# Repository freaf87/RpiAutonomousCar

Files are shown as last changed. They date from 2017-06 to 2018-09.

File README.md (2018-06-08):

Rpi Autonomous Car PCB 
====================
This board bring those additional functions below to the Raspberry pi:

	 - Analog Digital Converter with MCP3008 (8)
	 - DC Brushed Motor driver (2) with TB6612FNG
	 - Level converted IOs (5V <-> 3.3V) (8)
     - 16-channel, 12-bit PWM with PCA9685
     - RGB LED (1)
     - Pushbutton (1)

Top                                                                      |  Bottom
:-----------------------------------------------------------------------:|:--------------------------------------------------------------:
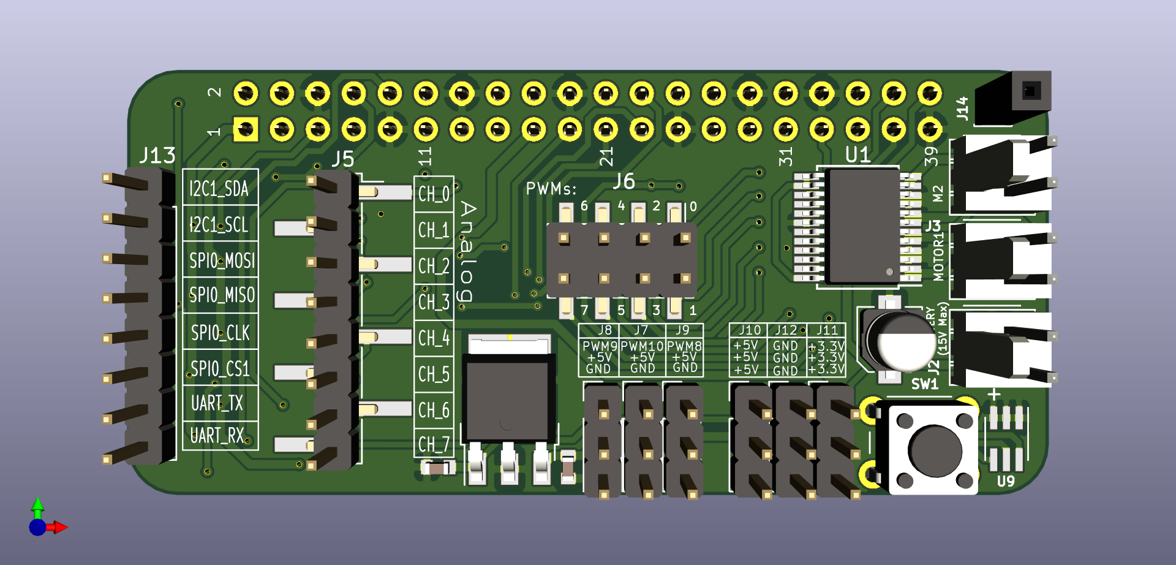
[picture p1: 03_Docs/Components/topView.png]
Top
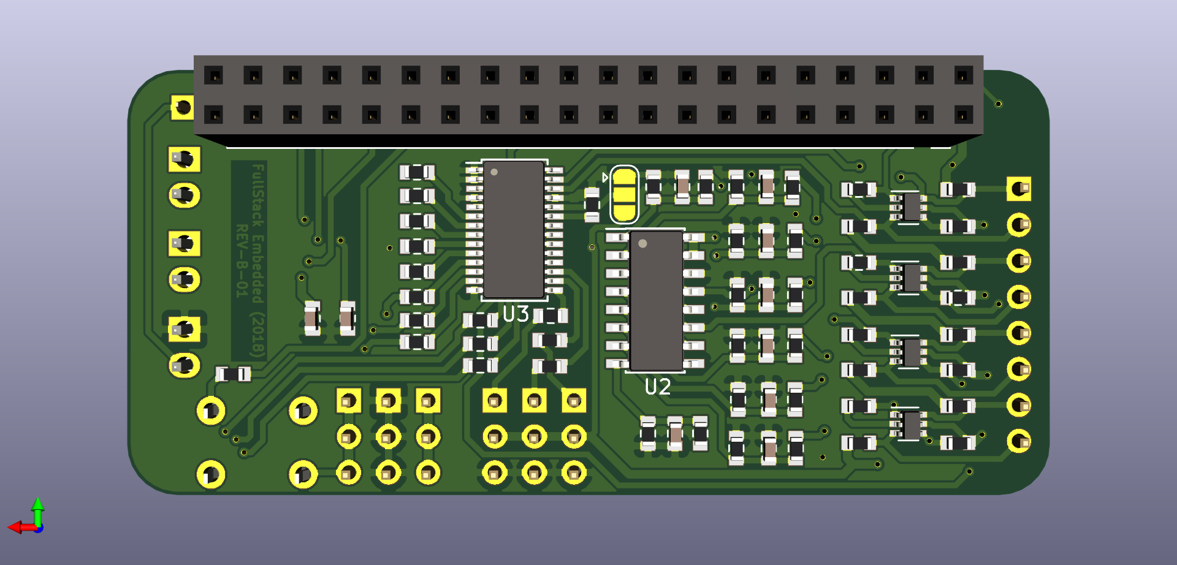
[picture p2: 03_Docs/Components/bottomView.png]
Bottom
  |  

Author: Frederic Afadjigla, 2018

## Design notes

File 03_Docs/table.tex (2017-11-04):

\begin{table}[htbp]
\caption{AutonomousCarPinout}
\begin{center}
\begin{tabular}{|c|c|c|c|c|c|}
\hline
\textbf{Pin number} & \textbf{Pin name} & \textbf{Pin type} & \textbf{Primary function} & \textbf{Level converted} & \textbf{Additional functions} \\ \hline
3 & GPIO 02 & I/O & I2C1 SDA  & JP1/5 &  \\ \hline
5 & GPIO 03 & I/O & I2C1 SCL  & JP1/6 &  \\ \hline
7 & GPIO 04 & I/O &  & - & SERVO PWM \\ \hline
8 & GPIO 14 & I/O & UART0 TX & JP1/7 &  \\ \hline
10 & GPIO 15 & I/O & UART0 RX & JP1/8 &  \\ \hline
11 & GPIO 17 & I/O &  & - &  \\ \hline
12 & GPIO 18 & I/O &  & - & ANTENNA\_1 \\ \hline
13 & GPIO 27 & I/O &  & - & ANTENNA\_2 \\ \hline
15 & GPIO 22 & I/O &  & - &  \\ \hline
16 & GPIO 23 & I/O &  & - &  \\ \hline
18 & GPIO 24 & I/O &  & - &  \\ \hline
19 & GPIO 10 & I/O & SPI0 MOSI & JP1/1 & ADC\_MOSI \\ \hline
21 & GPIO 09 & I/O & SPI0 MISO & JP1/2 & ADC\_MISO \\ \hline
22 & GPIO 25 & I/O &  & - & ADC\_CS \\ \hline
23 & GPIO 11 & I/O & SPI0 CLK & JP1/3 & ADC\_CLK \\ \hline
24 & GPIO 08 & I/O & SPI0 CS & JP1/4 &  \\ \hline
26 & GPIO 07 & I/O &  & - &  \\ \hline
29 & GPIO 05 & I/O &  & - & M1\_PWM \\ \hline
31 & GPIO 06 & I/O &  & - & M1\_DIR\_1 \\ \hline
32 & GPIO 12 & I/O &  & - & M1\_DIR\_2 \\ \hline
33 & GPIO 13 & I/O &  & - & STBY \\ \hline
35 & GPIO 19 & I/O &  & - & M2\_DIR\_1 \\ \hline
36 & GPIO 16 & I/O &  & - & M2\_DIR\_2 \\ \hline
37 & GPIO 26 & I/O &  & - & M2\_PWM \\ \hline
38 & GPIO 20 & I/O &  & - &  \\ \hline
40 & GPIO 21 & I/O & \multicolumn{1}{l|}{} & - & USER LED \\ \hline
\end{tabular}
\end{center}
\label{AutonomousCarPinout}
\end{table}

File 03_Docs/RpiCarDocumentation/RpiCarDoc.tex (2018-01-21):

\documentclass[
12pt, % Main document font size
a4paper, % Paper type, use 'letterpaper' for US Letter paper
oneside, % One page layout (no page indentation)
%twoside, % Two page layout (page indentation for binding and different headers)
headinclude,footinclude, % Extra spacing for the header and footer
BCOR5mm, % Binding correction
table,
]{scrartcl}

\input{structure.tex} % Include the structure.tex file which specified the document structure and layout

\hyphenation{Fortran hy-phen-ation} % Specify custom hyphenation points in words with dashes where you would like hyphenation to occur, or alternatively, don't put any dashes in a word to stop hyphenation altogether

%----------------------------------------------------------------------------------------
%	TITLE AND AUTHOR(S)
%----------------------------------------------------------------------------------------

\title{\normalfont\spacedallcaps{RPi based autonomous Car}} % The article title
\author{\spacedlowsmallcaps{Fullstack Embedded (2017)} \\\spacedlowsmallcaps{Frederic Afadjigla}} 
\date{} % An optional date to appear under the author(s)

%----------------------------------------------------------------------------------------

\usepackage{graphicx}
\begin{document}

%----------------------------------------------------------------------------------------
%	HEADERS
%----------------------------------------------------------------------------------------

\renewcommand{\sectionmark}[1]{\markright{\spacedlowsmallcaps{#1}}} % The header for all pages (oneside) or for even pages (twoside)
%\renewcommand{\subsectionmark}[1]{\markright{\thesubsection~#1}} % Uncomment when using the twoside option - this modifies the header on odd pages
\lehead{\mbox{\llap{\small\thepage\kern1em\color{halfgray} \vline}\color{halfgray}\hspace{0.5em}\rightmark\hfil}} % The header style

\pagestyle{scrheadings} % Enable the headers specified in this block

%----------------------------------------------------------------------------------------
%	TABLE OF CONTENTS & LISTS OF FIGURES AND TABLES
%----------------------------------------------------------------------------------------
\maketitle % Print the title/author/date block

\setcounter{tocdepth}{2} % Set the depth of the table of contents to show sections and subsections only

\tableofcontents % Print the table of contents
\listoffigures % Print the list of figures
%\listoftables % Print the list of tables

%----------------------------------------------------------------------------------------
%	ABSTRACT
%----------------------------------------------------------------------------------------

\section*{Abstract} % This section will not appear in the table of contents due to the star (\section*)
The purpose of this document is to give the reader an overview about the RpiAutonomousCar's hardware. This will be the learning platform for the FSE 2017 Workshop in Lomé and Accra. The principal hardware components of the board and interfaces will be briefly described.

%
\newpage
%

%----------------------------------------------------------------------------------------
%	INTRODUCTION
%----------------------------------------------------------------------------------------

\section{Introduction}
Goal of FSE 2017 will be to build an autonomous car with obstacle avoidance capability with the students. The robot should be able to drive 2 brushed DC motors, an ultrasonic sensor for distance measurement and a servo motor. To be able to fullfill these requirements with a Raspberry Pi, an additional board will be designed.

%----------------------------------------------------------------------------------------
%	MECHANIC
%----------------------------------------------------------------------------------------

\section{RpiAutonomousCar's mechanic}
As shown in Figure~\vref{fig:Mechanic1} and ~\vref{fig:Mechanic2}, the mechanical structure is simple and easy to build. The kit includes:
\begin{itemize}
\item 1 x Car Chassis 
\item 2 x Gear Motor(1:48) 
\item 2 x Car Tire 
\item 2 x Speed Encoder 
\item 2 x Fastener 
\item 1 x Universal Wheel 
\item 1 x Battery Box 
\item All Necessary Screw And Nut
\end{itemize}

\begin{figure}[h]
\minipage{0.48\textwidth}
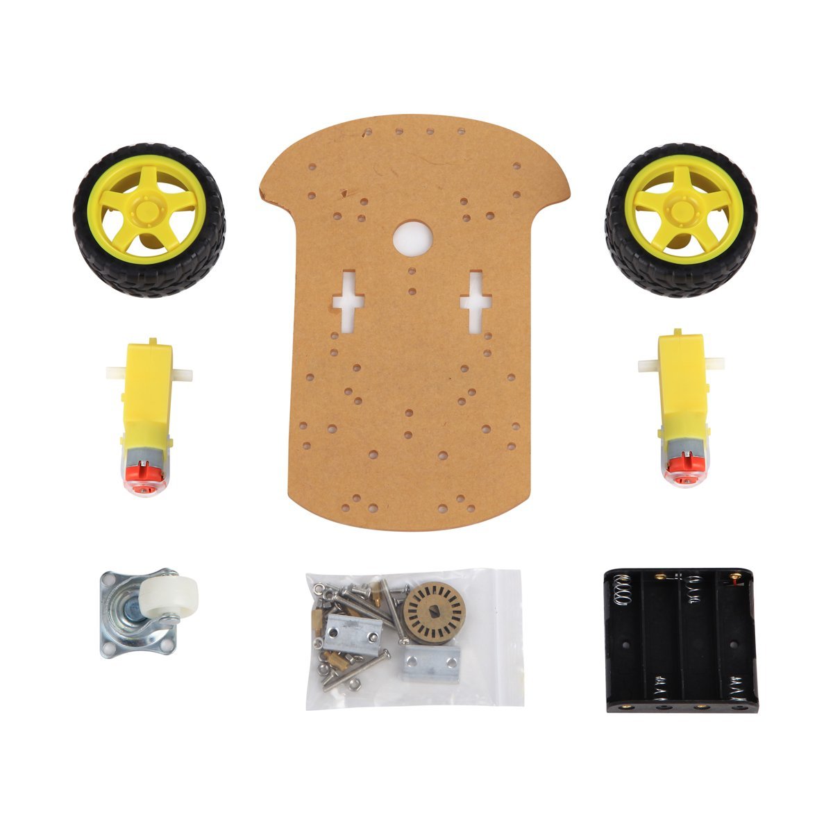
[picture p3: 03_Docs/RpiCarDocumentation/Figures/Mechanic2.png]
  
  \caption{Robot's components}\label{fig:Mechanic2}
\endminipage\hfill
\minipage{0.48\textwidth}
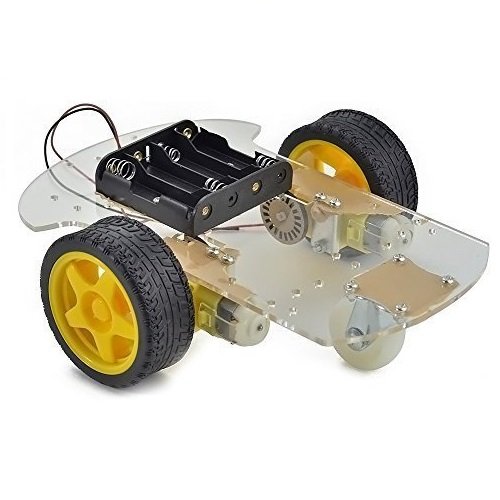
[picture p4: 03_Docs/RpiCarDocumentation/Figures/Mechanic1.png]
  
  \caption{Assembled robot}\label{fig:Mechanic1}
\endminipage
\end{figure}

%----------------------------------------------------------------------------------------
%	ELECTRONIC
%----------------------------------------------------------------------------------------
\section{RpiAutonomousCar's electronic}
The Board's electronic is kept simple to ease training. It is designed so that students can use the same board to design other embedded system examples.

\subsection{Led}
The RpiAutonomousCar's board has one led connected to GPIO21.

\begin{figure}[H]
\centering
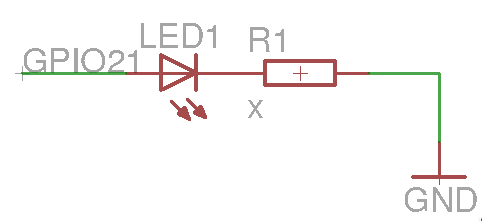
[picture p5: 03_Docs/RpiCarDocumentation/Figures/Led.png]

\caption{Led}
\label{Led}
\end{figure}

\subsection{Analog Inputs for Raspberry Pi Using the MCP3004}
The MCP3004 is a low cost 4-channel 10-bit analog to digital converter. The MCP3004 connects to the Raspberry Pi using a serial peripheral interface (SPI) serial connection. You can use either the hardware SPI bus (remember to connect GPIO07 and GPIO25 together via a jumper cable if you have the first version of the board), or any four GPIO pins and software SPI to communicate to the MCP3004. Software SPI is a little more flexible since it can work with any pins on the Pi, whereas hardware SPI is slightly faster but less flexible because it only works with specific pins. The board gives you the possibility to try both methods since it is also wired to the Raspberry Pi hardware SPI.

\begin{figure}[h]
\centering
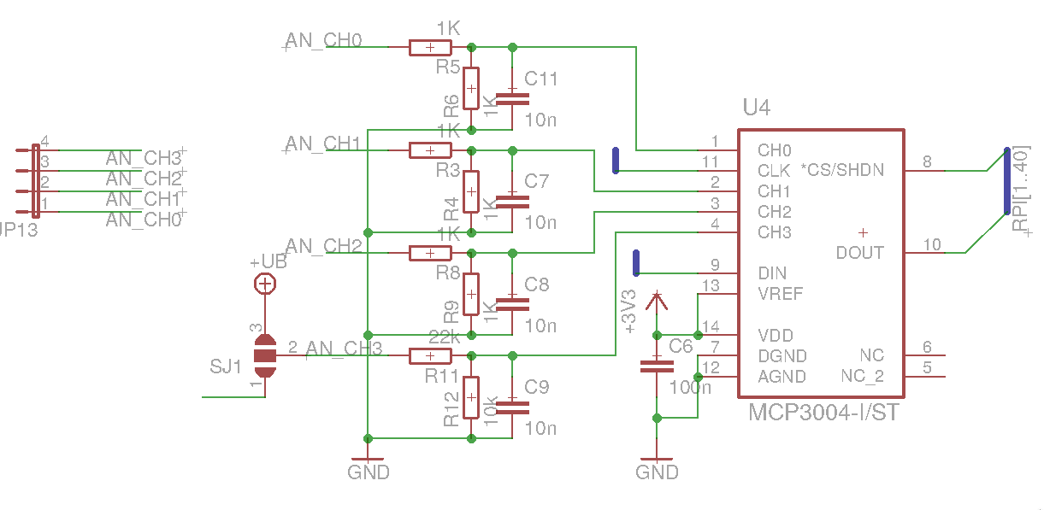
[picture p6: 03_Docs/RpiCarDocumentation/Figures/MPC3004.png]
 
\caption[MPC3004 schematic]{MPC3004 schematic}
\label{fig:MPC3004}
\end{figure}

\begin{table}[H]
\centering
\begin{tabular}{lr}
\hline
SPI Pins & Raspberry Pi pin \\
\hline
SCLK (Serial Clock)        & GPIO11 \\
MOSI (Master Out Slave In) & GPIO10 \\
MISO (Master In Slave Out) & GPIO09 \\
CS   (Chip Select)         & GPIO25 \\
\hline
\end{tabular}
\label{tab:label}
\caption{MCP3004 SPI connection}
\end{table}
Voltage that are allowed to be connected to the MCP3004 have to be selected so that \(V_{out}\) muss be less than 3.3V(\(V_{ref}\)). \(V_{out}\) is the voltage that can be measured after the voltage dividers. All channels except channel 3 are designed to have a measuring range of 0-5V DC. Channel 3 can measure up to 10V.
\(V_{out[0-2]}\) for channels 0,1,2 can be calculated as:

\[ V_{ out[0-2] } = \frac{ R_{6} }{ R_{5} + R_{6} } * V_{in}  = 0.5* V_{in}\]

In case of channel 3:

\[ V_{out[3]} = 0.316 * V_{in}\]

Please note that the analog channel 3 is connected per default via a jumper (SJ1) to the robot's supply voltage. Remove the jumper to be able to connect another voltage source to channel 3. 

\subsection{8-channel Bi-directional Logic Level Converter - TXB0108}
Precautions have to be taken when connecting 5V devices to the raspberry pi since the Pi is not 5V tolerant. There are many simple ways to handle this issue like voltage dividers.Handling bidirectional signals or high speed transfers can be tough. That's where this lovely chip, the TXB0108 bi-directional level converter comes in! This chip performs bidirectional level shifting from pretty much any voltage to any voltage and will auto-detect the direction.  

\begin{figure}[h]
\centering
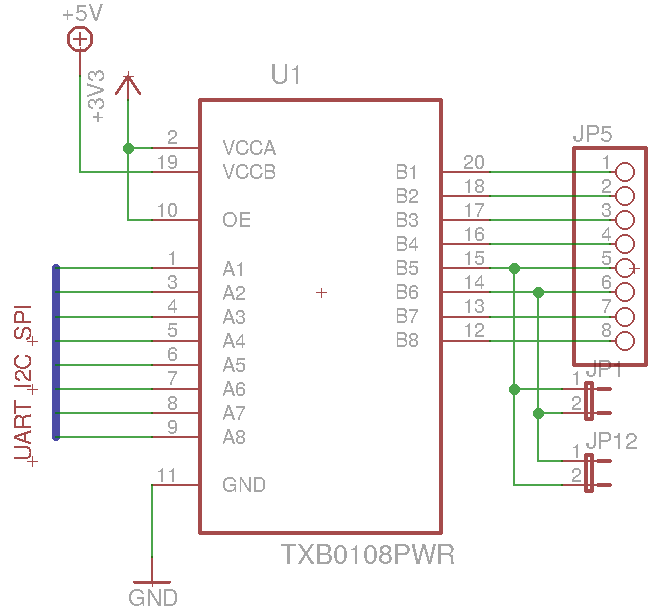
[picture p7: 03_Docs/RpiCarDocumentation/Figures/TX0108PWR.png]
 
\caption[TX0108PWR schematic]{TXB0108PWR schematic}
\label{fig:TX0108PWR}
\end{figure}

\begin{table}[H]
\centering
\begin{tabular}{|cc|}
\hline
Pins & RPi pin \\
\hline
1  & GPIO10 \\
2  & GPIO09 \\
3  & GPIO11 \\
4  & GPIO08 \\
5  & GPIO02 \\
6  & GPIO03 \\
7  & GPIO14 \\
8  & GPIO15 \\
\hline
\end{tabular}
\label{tab:label}
\caption{TX0108PWR connection}
\end{table}
\subsection {DC Motor driver - TB6612FNG}
The TB6612FNG motor driver can control up to two DC motors at a constant current of 1.2A (3.2A peak). Two input signals (IN1 and IN2) can be used to control the motor in one of four function modes - clockwise (CW), counter-clockwise (CCW), short-brake, and stop. The two motor outputs (A and B) can be separately controlled, the speed of each motor is controlled via a PWM input signal with a frequency up to 100kHz. The STBY pin should be pulled high to take the motor out of standby mode.

Logic supply voltage (VCC) can be in the range of 2.7-5.5VDC, while the motor supply (VM) is limited to a maximum voltage of 15VDC. The output current is rated up to 1.2A per channel (or up to 3.2A for a short, single pulse).\\

Features:
\begin{itemize}
\item[•] Power supply voltage: VM=15V max, VCC=2.7-5.5V
\item[•] Output current: Iout=1.2A(average) / 3.2A (peak)
\item[•] Standby control to save power
\item[•] CW/CCW/short brake/stop motor control modes
\item[•] Built-in thermal shutdown circuit and low voltage detecting circuit
\item[•] All pins of the TB6612FNG broken out to 0.1" spaced pins
\item[•] Filtering capacitors on both supply lines
\end{itemize}

\begin{figure}[H]
\centering
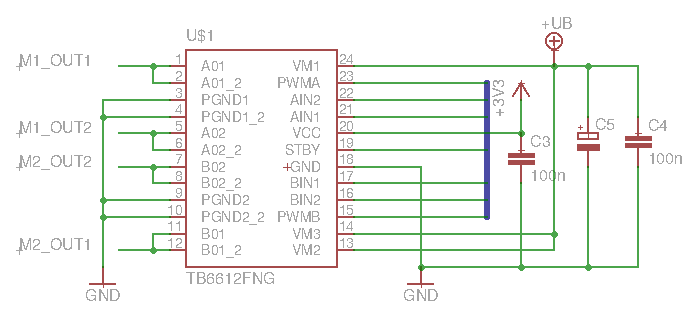
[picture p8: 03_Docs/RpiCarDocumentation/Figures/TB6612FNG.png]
 
\caption[TB6612FNG schematic]{TB6612FNG schematic}
\label{fig:TB6612FNG}
\end{figure}
Let’s discuss the pinout for the TB6612FNG:

\newcolumntype{b}{X}
\newcolumntype{s}{>{\hsize=.3\hsize}X}
\newcolumntype{m}{>{\hsize=.5\hsize}X}

\begin{table}[H]
\centering
\begin{adjustwidth}{-1cm}{}
\resizebox{16cm}{!} {%
\begin{tabularx}{18cm}{smb}
\hline
Pin Label & Function & Notes \\
\hline
VM & Motor Voltage  & This is where you provide power for the motors (2.2V to 13.5V)\\
VCC & Logic Voltage & This is the voltage to power the chip and talk to the microcontroller (2.7V to 5.5V)\\
GND & Ground  & Common Ground for both motor voltage and logic voltage (all GND pins are connected)\\
STBY & Standby & Allows the H-bridges to work when high (has a pulldown resistor so it must actively pulled high)\\
AIN1/BIN1 & Input 1 for channels A/B   & One of the two inputs that determines the direction\\
AIN2/BIN2 & Input 2 for channels A/B   & One of the two inputs that determines the direction\\
PWMA/PWMB & PWM input for channels A/B & PWM input that controls the speed\\
A01/B01 & Output 1 for channels A/B  & One of the two outputs to connect the motor\\
A02/B02 & Output 2 for channels A/B  & One of the two outputs to connect the motor\\
\hline
\end{tabularx} } 
\end{adjustwidth}
\label{tab:label}
\caption{TB6612FNG connection}
\end{table}

When the outputs are set to High/Low your motor will run. When they are set to Low/High the motor will run in the opposite direction. In both cases, the speed is controlled by the PWM input.

\begin{table}[H]
\centering
\begin{tabular}{llllll}
\hline
In1  & In2 & PWM & Out1 & Out2 & Mode \\
\hline
H    & H   & H/L & L    &L     & Short brake\\
L    & H   & H   & L    & H    & CCW\\
L    & H   & L   & L    & L    & Short brake\\
H    & L   & H   & H    & L    & CW\\
H    & L   & L   & L    & L    & Short brake\\
L    & L   & H   & OFF  & OFF  & Stop\\
\hline
\end{tabular}
\caption{TB6612FNG Logic}
\label{tab:label}
\end{table}

\section{Wiring the RpiCar}
\subsection{Connecting Robot's components}

\begin{figure}[H]
\centering
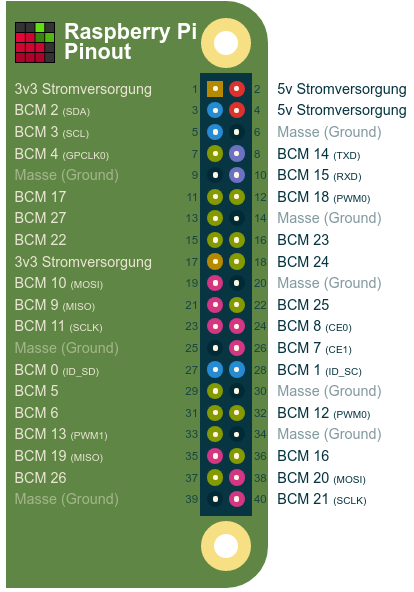
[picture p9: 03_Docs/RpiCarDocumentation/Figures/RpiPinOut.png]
 
\caption[Raspberry Pi Pinout]{Raspberry Pi Pinout \footnotemark}
\label{fig:Raspberry Pi Pinout}
\end{figure}
\footnotetext{\url{https://de.pinout.xyz/pinout/}}

\begin{itemize}

\item Connecting M1 and M2\\
M1 = Motor left and M2 = Motor right
	\begin{figure}[H]
	\centering
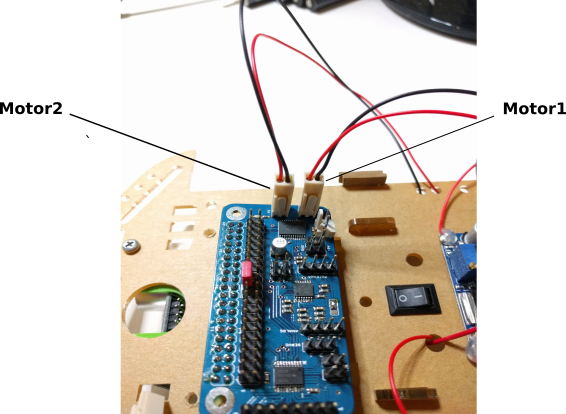
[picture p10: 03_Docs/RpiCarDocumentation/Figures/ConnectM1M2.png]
	
	\caption{Connecting Motor1 and Motor2}
	\label{Connectng Motor1 and Motor2 }
	\end{figure}
	
\item Connecting Motors PWR and Rpi PWR \\
	\begin{figure}[H]
	\centering
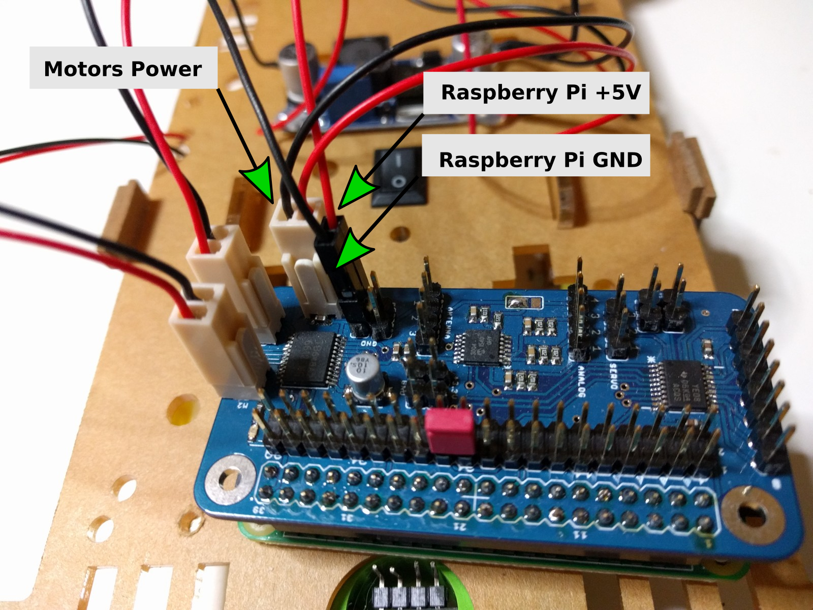
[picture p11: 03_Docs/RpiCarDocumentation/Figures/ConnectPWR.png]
	
	\caption{Connecting Motors PWR and Rpi PWR}
	\label{Connecting Motors PWR and Rpi PWR }
	\end{figure}

\item Connecting Motor Driver Pins\\
Note: Wiring the motor driver is only needed vor V01 of the board. Later releases of the board will incorporate those changes. 

Please connect those pins below together:

    M1 PwmPinAnnex = \textcolor{red}{5}    .......   m1pwmpin = \textcolor{red}{18}
    
    M2 PwmPinAnnex = \textcolor{blue}{26}   .....  m2pwmpin = \textcolor{blue}{13}

\item Connecting the ultrasonic sensor
	\begin{table}[H]
	\centering
	\begin{tabular}{ll}
	\hline
	   Function & Rpi Pin\\
	\hline
		VCC & +5V\\
		TRIG & 15 \textcolor{red}{(Level converted)}\\
		ECHO & 14 \textcolor{red}{(Level converted)}\\
		GND & GND\\
	\hline
	\end{tabular}
	\end{table}
Refer to table ... to find out where GPIO14 and GPIO15 are routed
\item Connecting the IR sensor for line following \\ 
IR sensor can be connected to any available GPIO when used in digital mode. If you want more accuracy analog mode can also be used. Therefore the MCP3004 chip has to be used. Connect the sensor output to the available pins of the MCP3004
\end{itemize}

\end{document}

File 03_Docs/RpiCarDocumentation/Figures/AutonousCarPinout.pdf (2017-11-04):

Sheet1

Pin

n

u

m

b

er

| Pin name | | Primary function | | Additional functions
3 | GPIO 02 | I/O | I2C1 SDA | JP1/5
5 | GPIO 03 | I/O | I2C1 SCL | JP1/6
7 | GPIO 04 | I/O | | - | SERVO PWM
8 | GPIO 14 | I/O | UART0 TX | JP1/7
10 | GPIO 15 | I/O | UART0 RX | JP1/8
11 | GPIO 17 | I/O | | -
12 | GPIO 18 | I/O | | - | ANTENNA_1
13 | GPIO 27 | I/O | | - | ANTENNA_2
15 | GPIO 22 | I/O | | -
16 | GPIO 23 | I/O | | -
18 | GPIO 24 | I/O | | -
19 | GPIO 10 | I/O | SPI0 MOSI | JP1/1 | ADC_MOSI
21 | GPIO 09 | I/O | SPI0 MISO | JP1/2 | ADC_MISO
22 | GPIO 25 | I/O | | - | ADC_CS
23 | GPIO 11 | I/O | SPI0 CLK | JP1/3 | ADC_CLK
24 | GPIO 08 | I/O | SPI0 CS | JP1/4
26 | GPIO 07 | I/O | | -
29 | GPIO 05 | I/O | | - | M1_PWM
31 | GPIO 06 | I/O | | - | M1_DIR_1
32 | GPIO 12 | I/O | | - | M1_DIR_2
33 | GPIO 13 | I/O | | - | STBY
35 | GPIO 19 | I/O | | - | M2_DIR_1
36 | GPIO 16 | I/O | | - | M2_DIR_2
37 | GPIO 26 | I/O | | - | M2_PWM
38 | GPIO 20 | I/O | | -
40 | GPIO 21 | I/O | | - | USER LED

Pin ty

p

e

L

e

v

el c

o

n

v

erte

d

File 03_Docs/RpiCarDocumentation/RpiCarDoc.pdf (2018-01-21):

# R P I B A S E D A U T O N O M O U S C A R

fullstack embedded (2017)

frederic afadjigla

contents

1 | Introduction | 3
2 | RpiAutonomousCar’s mechanic | 3
3 | RpiAutonomousCar’s electronic | 4
3.1 | Led | | 4
3.2 | Analog Inputs for Raspberry Pi Using the MCP3004 | | 4
3.3 | 8-channel Bi-directional Logic Level Converter - TXB0108 . . | 5
3.4 | DC Motor driver - TB6612FNG | | 6
4 | Wiring the RpiCar | 9
4.1 | Connecting Robot’s components | | 9

list of figures

Figure 1 | Robot’s components | | 3
Figure 2 | Assembled robot | | 3
Figure 3 | Led | | 4
Figure 4 | MPC3004 schematic | | 5
Figure 5 | TX0108PWR schematic | | 6
Figure 6 | TB6612FNG schematic | | 7
Figure 7 | Raspberry Pi Pinout | | 9
Figure 8 | Connecting Motor1 and Motor2 | | 10
Figure 9 | Connecting Motors PWR and Rpi PWR | | 10

1

List of Figures 2

abstract

The purpose of this document is to give the reader an overview about the RpiAutonomousCar’s hardware. This will be the learning platform for the FSE 2017 Workshop in Lomé and Accra. The principal hardware components of the board and interfaces will be briefly described.

introduction | 3
1 | introduction

Goal of FSE 2017 will be to build an autonomous car with obstacle avoidance capability with the students. The robot should be able to drive 2 brushed DC motors, an ultrasonic sensor for distance measurement and a servo motor. To be able to fullfill these requirements with a Raspberry Pi, an additional board will be designed.

2 rpiautonomouscar’s mechanic

As shown in Figure 2 and 1, the mechanical structure is simple and easy to build. The kit includes:

- 1 x Car Chassis
- 2 x Gear Motor(1:48)
- 2 x Car Tire
- 2 x Speed Encoder
- 2 x Fastener
- 1 x Universal Wheel
- 1 x Battery Box
- All Necessary Screw And Nut


Figure 1: Robot’s components | Figure 2: Assembled robot

rpiautonomouscar’s electronic | 4
3 | rpiautonomouscar’s electronic

The Board’s electronic is kept simple to ease training. It is designed so that students can use the same board to design other embedded system examples.

3.1 Led

The RpiAutonomousCar’s board has one led connected to GPIO21.

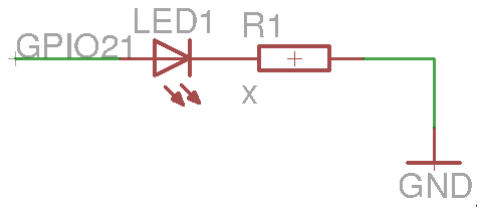
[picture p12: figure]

Figure 3: Led

3.2 Analog Inputs for Raspberry Pi Using the MCP3004

The MCP3004 is a low cost 4-channel 10-bit analog to digital converter. The MCP3004 connects to the Raspberry Pi using a serial peripheral interface (SPI) serial connection. You can use either the hardware SPI bus (remember to connect GPIO07 and GPIO25 together via a jumper cable if you have the first version of the board), or any four GPIO pins and software SPI to communicate to the MCP3004. Software SPI is a little more flexible since it can work with any pins on the Pi, whereas hardware SPI is slightly faster but less flexible because it only works with specific pins. The board gives you the possibility to try both methods since it is also wired to the Raspberry Pi hardware SPI.

SPI Pins | Raspberry Pi pin
SCLK (Serial Clock) | GPIO11
MOSI (Master Out Slave In) | GPIO10
MISO (Master In Slave Out) | GPIO09
CS (Chip Select) | GPIO25

Table 1: MCP3004 SPI connection

Voltage that are allowed to be connected to the MCP3004 have to be selected so that Vout muss be less than 3.3V(Vref). Vout is the voltage that can be measured after the voltage dividers. All channels except channel

rpiautonomouscar’s electronic | 5

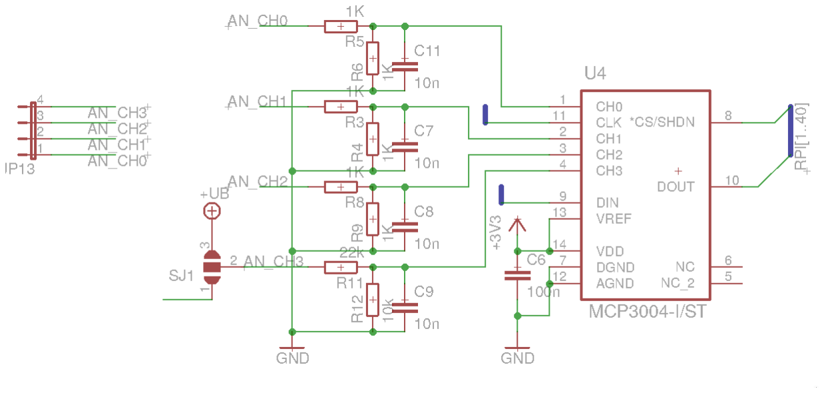
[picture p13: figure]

Figure 4: MPC3004 schematic

3 are designed to have a measuring range of 0-5V DC. Channel 3 can measure up to 10V. Vout[0−2]

for channels 0,1,2 can be calculated as:

Vout[0−2] =

R6
R5 + R6

∗ Vin = 0.5 ∗ Vin

In case of channel 3:

Vout[3] = 0.316 ∗ Vin

Please note that the analog channel 3 is connected per default via a jumper (SJ1) to the robot’s supply voltage. Remove the jumper to be able to connect another voltage source to channel 3.

3.3 8-channel Bi-directional Logic Level Converter - TXB0108

Precautions have to be taken when connecting 5V devices to the raspberry pi since the Pi is not 5V tolerant. There are many simple ways to handle this issue like voltage dividers.Handling bidirectional signals or high speed transfers can be tough. That’s where this lovely chip, the TXB0108 bi-directional level converter comes in! This chip performs bidirectional level shifting from pretty much any voltage to any voltage and will autodetect the direction.

rpiautonomouscar’s electronic | 6


Figure 5: TXB0108PWR schematic

Pins RPi pin
1 | GPIO10
2 | GPIO09
3 | GPIO11
4 | GPIO08
5 | GPIO02
6 | GPIO03
7 | GPIO14
8 | GPIO15

Table 2: TX0108PWR connection

3.4 DC Motor driver - TB6612FNG

The TB6612FNG motor driver can control up to two DC motors at a constant current of 1.2A (3.2A peak). Two input signals (IN1 and IN2) can be used to control the motor in one of four function modes - clockwise (CW), counter-clockwise (CCW), short-brake, and stop. The two motor outputs (A and B) can be separately controlled, the speed of each motor is controlled via a PWM input signal with a frequency up to 100kHz. The STBY pin should be pulled high to take the motor out of standby mode.
Logic supply voltage (VCC) can be in the range of 2.7-5.5VDC, while the motor supply (VM) is limited to a maximum voltage of 15VDC. The output current is rated up to 1.2A per channel (or up to 3.2A for a short,

rpiautonomouscar’s electronic | 7

single pulse).

Features:

- Power supply voltage: VM=15V max, VCC=2.7-5.5V
- Output current: Iout=1.2A(average) / 3.2A (peak)
- Standby control to save power
- CW/CCW/short brake/stop motor control modes
- Built-in thermal shutdown circuit and low voltage detecting circuit
- All pins of the TB6612FNG broken out to 0.1" spaced pins
- Filtering capacitors on both supply lines


Figure 6: TB6612FNG schematic

Let’s discuss the pinout for the TB6612FNG:

rpiautonomouscar’s electronic | 8
Pin Label | Function | Notes
VM | Motor Voltage | This is where you provide power for the motors
(2.2V to 13.5V)
VCC | Logic Voltage | This is the voltage to power the chip and talk to
the microcontroller (2.7V to 5.5V)
GND | Ground | Common Ground for both motor voltage and
logic voltage (all GND pins are connected)
STBY | Standby | Allows the H-bridges to work when high (has
a pulldown resistor so it must actively pulled high)
AIN1/BIN1 | Input 1 | for channels
A/B

One of the two inputs that determines the direction
AIN2/BIN2 | Input 2 | for channels
A/B

One of the two inputs that determines the direction
PWMA/PWMB PWM input for channels A/B

PWM input that controls the speed

A01/B01 | Output 1 | for channels
A/B

One of the two outputs to connect the motor

A02/B02 | Output 2 | for channels
A/B

One of the two outputs to connect the motor

Table 3: TB6612FNG connection

When the outputs are set to High/Low your motor will run. When they are set to Low/High the motor will run in the opposite direction. In both cases, the speed is controlled by the PWM input.

In1 | In2 | PWM Out1 | Out2 | Mode
H | H | H/L | L | L | Short brake
L | H | H | L | H | CCW
L | H | L | L | L | Short brake
H | L | H | H | L | CW
H | L | L | L | L | Short brake
L | L | H | OFF | OFF | Stop

Table 4: TB6612FNG Logic

wiring the rpicar | 9
4 | wiring the rpicar
4.1 | Connecting Robot’s components


Figure 7: Raspberry Pi Pinout 1

- Connecting M1 and M2
M1 = Motor left and M2 = Motor right

1 https://de.pinout.xyz/pinout/

wiring the rpicar | 10

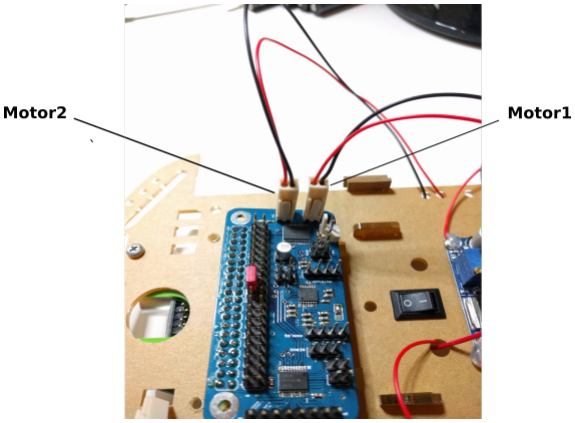
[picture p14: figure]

Figure 8: Connecting Motor1 and Motor2

- Connecting Motors PWR and Rpi PWR


Figure 9: Connecting Motors PWR and Rpi PWR

- Connecting Motor Driver Pins
Note: Wiring the motor driver is only needed vor V01 of the board. Later releases of the board will incorporate those changes.
Please connect those pins below together:
M1 PwmPinAnnex = 5 ....... m1pwmpin = 18

wiring the rpicar | 11

M2 PwmPinAnnex = 26 ..... m2pwmpin = 13

- Connecting the ultrasonic sensor

Function Rpi Pin
VCC | +5V
TRIG | 15 (Level converted)
ECHO | 14 (Level converted)
GND | GND
- Connecting the IR sensor for line following
IR sensor can be connected to any available GPIO when used in digital mode. If you want more accuracy analog mode can also be used. Therefore the MCP3004 chip has to be used. Connect the sensor output to the available pins of the MCP3004

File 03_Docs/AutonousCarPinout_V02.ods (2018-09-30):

Pin number | Pin name | Pin type | Used function | Level converted | Additional functions
3 | GPIO 02 | I/O | I2C1 SDA | JP1/5
5 | GPIO 03 | I/O | I2C1 SCL | JP1/6
7 | GPIO 04 | I/O |  | -
8 | GPIO 14 | I/O | UART0 TX | JP1/7
10 | GPIO 15 | I/O | UART0 RX | JP1/8
11 | GPIO 17 | I/O |  | -
12 | GPIO 18 | I/O |  | -
13 | GPIO 27 | I/O |  | - | IR_LEFT
15 | GPIO 22 | I/O |  | - | IR_MIDDLE
16 | GPIO 23 | I/O |  | - | IR_RIGHT
18 | GPIO 24 | I/O |  | -
19 | GPIO 10 | I/O | SPI_MOSI |  | ADC_MOSI
21 | GPIO 09 | I/O | SPI_MISO |  | ADC_MISO
22 | GPIO 25 | I/O |  | -
23 | GPIO 11 | I/O | SPI_CLK |  | ADC_CLK
24 | GPIO 08 | I/O | SPI_CS |  | ADC_CS
26 | GPIO 07 | I/O |  | -
29 | GPIO 05 | I/O |  | -
31 | GPIO 06 | I/O |  | -
32 | GPIO 12 | I/O | PWM0 | - | M1_PWM
33 | GPIO 13 | I/O | PWM1 | - | M2_PWM
35 | GPIO 19 | I/O |  | - | AIN1
36 | GPIO 16 | I/O |  | - | AIN2
37 | GPIO 26 | I/O |  | - | BIN1
38 | GPIO 20 | I/O |  | - | BIN2
40 | GPIO 21 | I/O |  | - | STBY
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

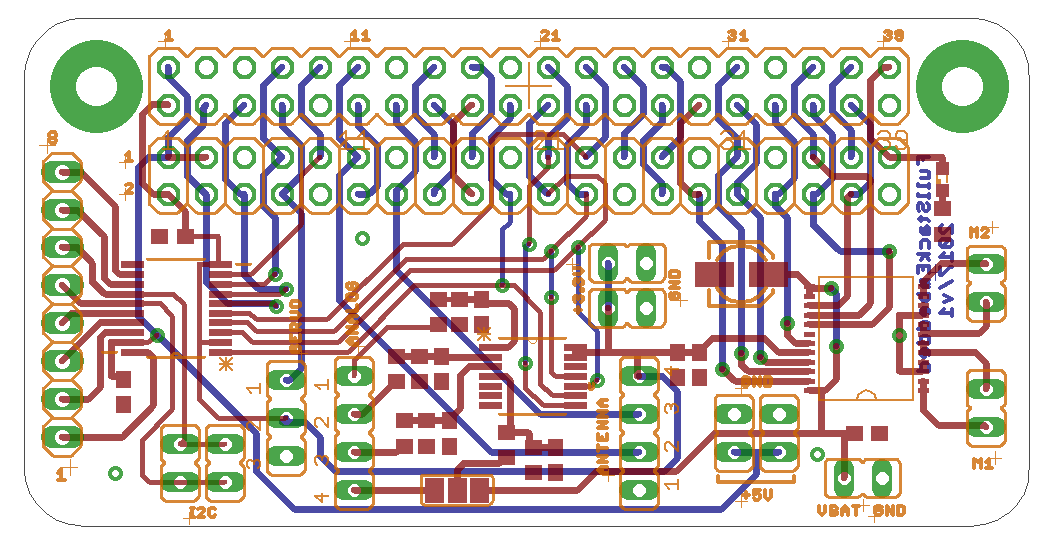
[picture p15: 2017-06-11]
03_Docs/RpiCarDocumentation/Figures/RpiCarBoard.png

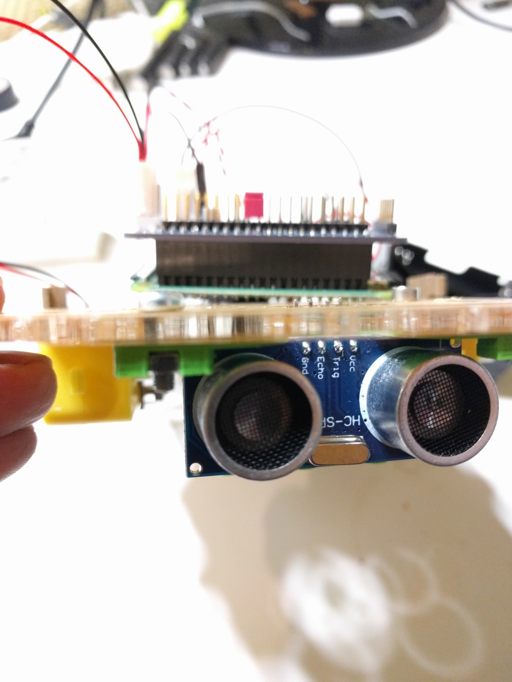
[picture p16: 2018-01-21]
03_Docs/RpiCarDocumentation/Figures/original/Ultrasonic.jpg

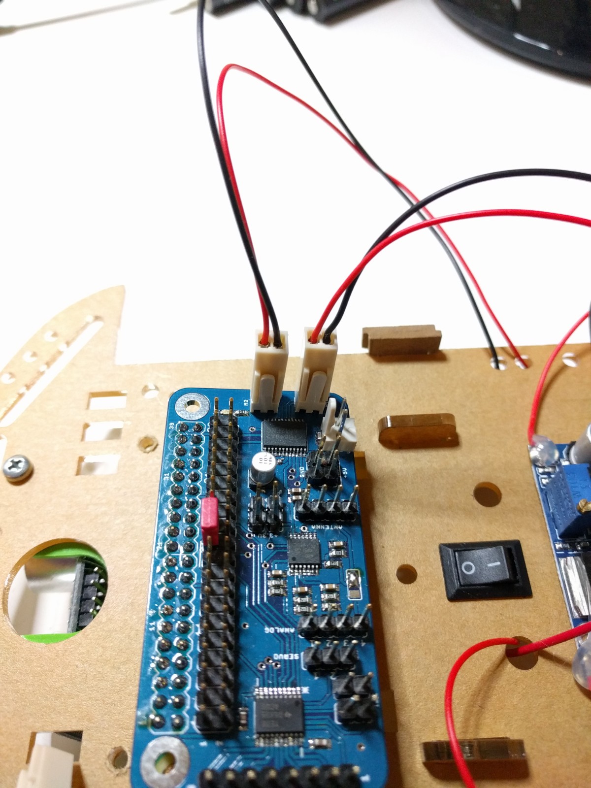
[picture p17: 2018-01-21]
03_Docs/RpiCarDocumentation/Figures/ConnectM1M2.jpg

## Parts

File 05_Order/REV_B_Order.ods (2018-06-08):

 | www.digikey.com
 | www.reichelt.de
 | Description | References | Value | Quantity | Prize | Total | Link
1 | Unpolarized capacitor | C12 | 0.33u | 1 | 0.1 | 0.1 | 311-2081-1-ND
2 | Unpolarized capacitor | C1 C3 | 100n | 2 | 0.132 | 0.264 | 445-12576-1-ND
3 | Unpolarized capacitor | C4 C5 C6 C7 C8 C9 C10 C11 C13 | 10n | 9 | 0.058 | 0.522 | 445-5662-1-ND
4 | Polarised capacitor | C2 | 10u | 1 | 0.24 | 0.24 | PCE3878CT-ND
5 | LED RGB, common anode (pin 1) | D1 | LED_ARGB | 1 | 0.47 | 0.47 | 516-3279-1-ND
6 | Generic connector, single row, 01x02 male | J2 J3 J4 | Conn_01x02 | 3 | 0.03 | 0.09 | PSS 254/2G
7 | Generic connector, single row, 01x02 female | J2 J3 J4 |  | 3 | 0.01 | 0.03 | PSK 254/2W
8 | Crimpkontakte für psk 254/ | J2 J3 J4 |  | 3 | 0.3 | 0.9 | PSK-KONTAKTE
9 | Generic connector, single row, 01x03, script generated (kicad-library-utils/schlib/autogen/connector/) | J7 J8 J9 J10 J11 J12 | Conn_01x03 | 6 | 0.0174 | 0.1044 | MPE 087-1-050
10 | Generic connector, single row, 01x08, script generated (kicad-library-utils/schlib/autogen/connector/) | J13 | Conn_01x08 | 1 | 0.1392 | 0.1392 | MPE 087-1-050
11 | Generic connector, single row, 01x08, script generated (kicad-library-utils/schlib/autogen/connector/) | J5 | Conn_01x08 | 1 | 0.46 | 0.46 | S1013EC-16-ND
12 | Generic connector, double row, 02x04, counter clockwise pin numbering scheme (similar to DIP packge numbering), script generated (kicad-library-utils/schlib/autogen/connector/) | J6 | Conn_02x04_Counter_Clockwise | 1 | 0.58 | 0.58 | SAM10794-ND
13 | Raspberry Pi | J1 | RaspberryPi | 1 |  | 0
14 | Resistor | R5 R6 R7 R8 R9 R30 R31 R32 R33 R34 R35 R36 R37 R38 R39 R40 R41 R42 R43 R44 R45 | 10k | 21 | 0.0321 | 0.6741 | RR08P10.0KDCT-ND
15 | Resistor | R1 R2 R3 R4 R10 R11 R12 R13 R48 | 1k | 9 | 0.0321 | 0.2889 | RR08P1.0KDCT-ND
16 | Resistor | R18 R19 R20 R21 R22 R23 R24 R25 R26 R27 R28 R29 R46 R47 | 220 | 14 | 0.0284 | 0.3976 | RHM220DCT-ND
17 | Resistor | R14 R15 R16 R17 | 22k | 4 | 0.0284 | 0.1136 | RHM22KDCT-ND
18 | Push button switch, generic, two pins | SW1 | SW_Push | 1 | 0.26 | 0.26 | P16765CT-ND
19 | MOSFET 2N-CH 60V 0.32A 6TSSOP | U4 U5 U6 U7 | BSS138PS | 4 | 0.64 | 2.56 | 497-7255-1-ND
20 | Positive 1.5A 35V Linear Regulator, Fixed Output 5V, TO-220/TO-263/TO-252 | U8 | L7805 | 1 | 0.64 | 0.64 | 497-7255-1-ND
21 | A/D Converter, 12-Bit, 8-Channel, SPI Interface , 2.7V-5.5V | U2 | MCP3008 | 1 | 1.93 | 1.93 | MCP3008T-I/SLCT-ND
22 | 16-channel 12-bit PWM Fm+ I2C-bus LED controller RGBA TSSOP | U3 | PCA9685PW | 1 | 1.93 | 1.93 | 568-8366-5-ND
23 | Driver IC for Dual DC motor, SSOP-24 | U1 | TB6612FNG | 1 | 1.8 | 1.8 | TB6612FNGC8ELCT-ND
 |  |  |  |  |  | 14.4938

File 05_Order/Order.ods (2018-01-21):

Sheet: RpiAutonomousCar
Total Price per kit (without Pi):
Pos |  |  | factor | Order price | subtotal
1 | Digikey order |  | 0.76 | 58.29 | 7.36
2 | reichelt order |  | 0.80 | 34.88 | 4.62
3 | Farnell order |  | 1.00 | 27.92 | 4.65
4 | PCB |  | 0.10 | 64.31 | 6.43
5 | Mechanic |  | 1.00 | 12.95 | 12.95 | https://www.amazon.de/gp/product/B01FTVHBME/ref=oh_aui_detailpage_o00_s00?ie=UTF8&psc=1
6 | Sensors & actuators
 |  | servo motor | 1.00 | 1.60 | 1.60 | https://www.amazon.de/gp/product/B00L8WN8GW/ref=oh_aui_detailpage_o09_s00?ie=UTF8&psc=1
 |  | ultrasonic range | 1.00 | 1.20 | 1.20 | https://www.amazon.de/gp/product/B00IZA1PYM/ref=oh_aui_detailpage_o02_s00?ie=UTF8&psc=1
 |  | Power module | 1.00 | 1.74 | 1.74 | https://www.amazon.de/gp/product/B009P04YTO/ref=oh_aui_detailpage_o03_s00?ie=UTF8&psc=1
 |  | Batterie (eneloop black serie) | 1.00 | 22.00 | 22.00 | https://www.amazon.de/Kraftmax-8er-Pack-Panasonic-Eneloop-Mignon/dp/B00KNVNNKA?s=ce-de
7 |  | others (kabeln, breadboard) | 1.00 | 5.00 | 5.00
 |  |  |  | Total: | 67.56

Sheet: Digikey_Order
Index | Menge | Teilenummer | Beschreibung | Einheitspreis EUR | Gesamtpreis | Costs for one single Board
1 | 10 | PCE4288CT-ND | CAP ALUM 10UF 20% 10V SMD | 0.23 | 2.3 | 1 | 0.23
2 | 8 | TB6612FNGC8ELCT-ND | IC MOTOR DRIVER PAR 24SSOP | 1.88 | 15.04 | 1 | 1.88
3 | 8 | MCP3004-I/ST-ND | IC ADC 10BIT 2.7V 4CH SPI14TSSOP | 1.9 | 15.2 | 1 | 1.9
4 | 20 | 311-1.0KGRCT-ND | RES SMD 1K OHM 5% 1/10W 0603 | 0.01 | 0.2 | 6 | 0.06
5 | 20 | 311-22KGRCT-ND | RES SMD 22K OHM 5% 1/10W 0603 | 0.01 | 0.2 | 1 | 0.01
6 | 40 | 311-1343-1-ND | CAP CER 0.1UF 50V Y5V 0603 | 0.018 | 0.72 | 5 | 0.09
8 | 6 | 754-1933-1-ND | LED BLUE CLEAR 0603 SMD | 0.54 | 3.24 | 1 | 0.54
9 | 10 | 311-10KGRCT-ND | RES SMD 10K OHM 5% 1/10W 0603 | 0.01 | 0.1 | 1 | 0.01
10 | 8 | 296-21527-1-ND | IC 8-BIT TRNSTR 15KV ESD 20TSSOP | 1.41 | 11.28 | 1 | 1.41
11 | 50 | 490-4516-1-ND | CAP CER 10000PF 50V X7R 0402 | 0.014 | 0.7 | 4 | 0.056
 |  |  |  | Zwischensumme | 48.98 |  | 6.186
 |  |  |  | Versand | 0
 |  |  |  | MwSt | 9.3062 |  | 1.17534
 |  |  |  | Gesamt | 58.2862 |  | 7.36134

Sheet: Reichelt_Order
Menge | Teilenummer | Beschreibung | Einheitspreis EUR | Gesamtpreis | Reale menge pro kit | preis pro kit
12 | MPE 087-2-040 | Stiftleisten 2,54 mm, 2X20, gerade | 0.62 | 7.44 | 2 | 1.24
6 | MPE 087-1-050 | Stiftleisten 2,54 mm, 1X50, gerade | 0.435 | 2.61 | 1 | 0.435
20 | PSS 254/2G | Printstecker, Einzelstecker, gerade, 2-polig | 0.02 | 0.4 | 3 | 0.06
5 | PSK-KONTAKTE | Crimpkontakte für psk 254/..., 20 Stück | 0.29 | 1.45 | 0.6 | 0.174
20 | PSK 254/2W | Kupplungs-Leergehäuse, Crimptechnik, 2-polig | 0.01 | 0.2 | 3 | 0.03
2 | SS 13ASP | Schiebeschalter 1x UM, stehend, Print, RM 4,7 | 0.99 | 1.98 | 1 | 0.99
1 | CR 44 | "No-Clean" SMD Lötpaste, 2,5ml in Spritze | 15.2 | 15.2 | 0.05 | 0.76
 |  |  | Zwischensumme | 29.28 |  | 3.689
 |  |  | Vesand | 5.6 |  | 0.933333333333333
 |  |  | MwSt | 0
 |  |  | Gesamt | 34.88 |  | 4.62233333333333

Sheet: Farnell_Order
Menge | Teilenummer | Beschreibung | Einheitspreis EUR | Gesamtpreis
6 |  | PSG-BB-170W - Steckplatine, 170 Pins, weiß, Kunststoff, 34.5mm breit | 1.51 | 9.06
6 |  | Batterie AA holder | 2.21 | 13.26
 |  |  | Zwischensumme | 22.32
 |  |  | Vesand | 5.6
 |  |  | MwSt | 0
 |  |  | Gesamt | 27.92

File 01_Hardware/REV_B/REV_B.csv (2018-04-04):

Id | Designator | Package | Quantity | Designation | Supplier and ref
1 | 100n1 | C_0603_1608Metric | 1 | C
2 | C1 | CP_Elec_4x4.5 | 1 | 10u
3 | C2 | C_0603_1608Metric | 1 | 100n
4 | C3,C4,C5,C6,C7,C8,C9,C10 | C_0603_1608Metric | 8 | 10n
5 | J1 | PinSocket_2x20_P2.54mm_Vertical | 1 | RaspberryPi
6 | J2,J3,J4 | Molex_KK-254_AE-6410-02A_1x02_P2.54mm_Vertical | 3 | Conn_01x02
7 | J6,J7,J8,J9,J10,J11,J13,J14,J15 | PinHeader_1x03_P2.54mm_Vertical | 9 | Conn_01x03
8 | J16 | PinHeader_1x08_P2.54mm_Vertical | 1 | Conn_01x08_Male
9 | R1,R2,R3,R4,R9,R10,R11,R12 | R_0603_1608Metric | 8 | 1k
10 | R5,R6,R7,R8,R17,R18,R19,R20,R21,R22,R23,R24,R25,R26,R27,R28,R29,R30,R31,R32 | R_0603_1608Metric | 20 | 10k
11 | R13,R14,R15,R16 | R_0603_1608Metric | 4 | 22k
12 | U5,U6,U7,U8 | SOT-363_SC-70-6 | 4 | BSS138PS
13 | U1 | SSOP-24_5.3x8.2mm_P0.65mm | 1 | TB6612FNG
14 | U2 | SOIC-16_3.9x9.9mm_P1.27mm | 1 | MCP3008
15 | U3 | TSSOP-28_4.4x9.7mm_P0.65mm | 1 | PCA9685PW
16 | J5 | PinHeader_1x08_P2.54mm_Vertical_SMD_Pin1Right | 1 | Conn_01x08_Male

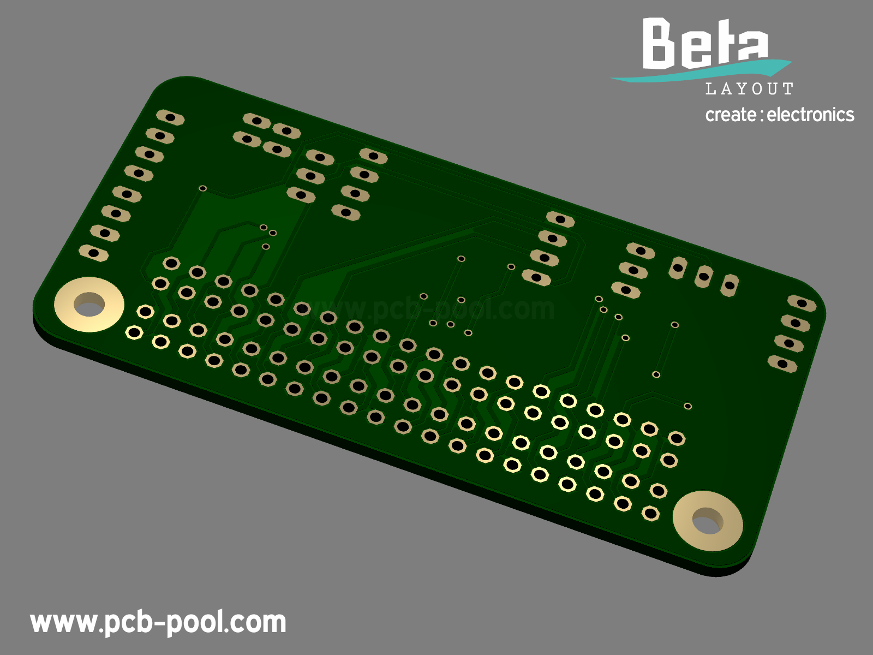
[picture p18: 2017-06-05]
03_Docs/Components/bot_gold_with_mask.png

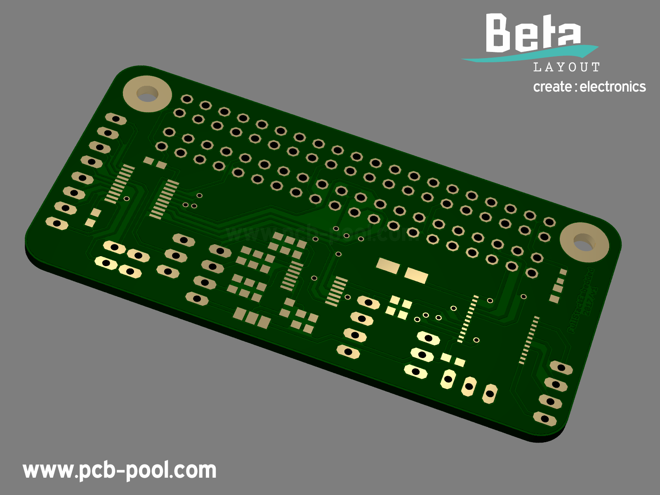
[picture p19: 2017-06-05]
03_Docs/Components/top_gold_with_mask.png

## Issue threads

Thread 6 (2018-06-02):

Fix I2C address PCA9685PW

freaf87, 2018-06-02:

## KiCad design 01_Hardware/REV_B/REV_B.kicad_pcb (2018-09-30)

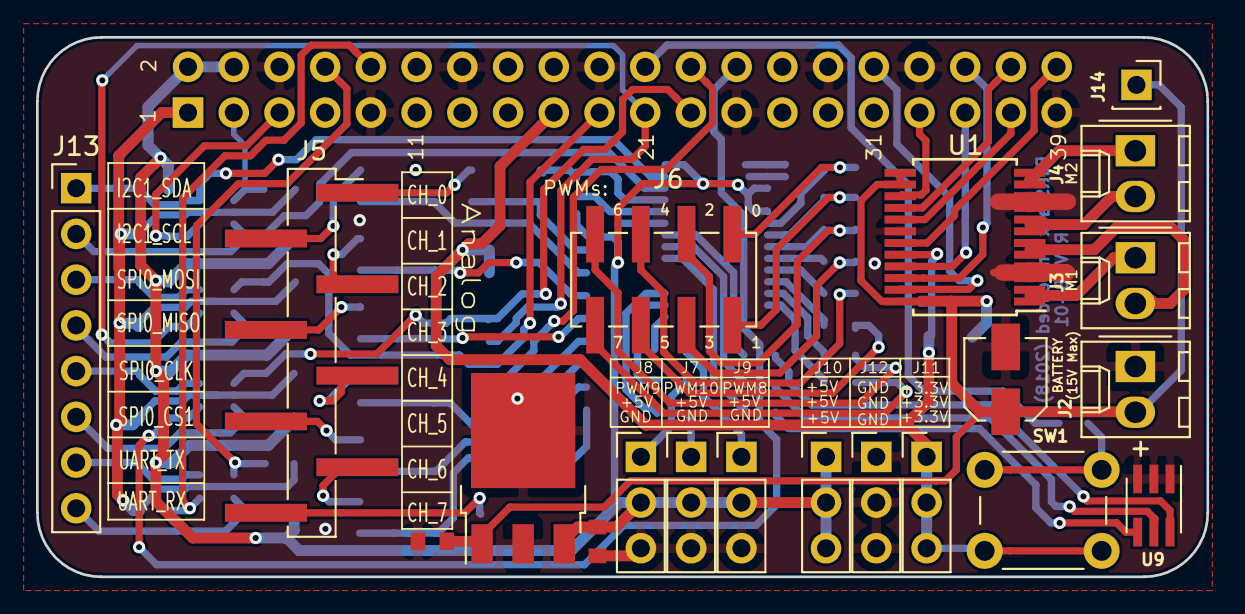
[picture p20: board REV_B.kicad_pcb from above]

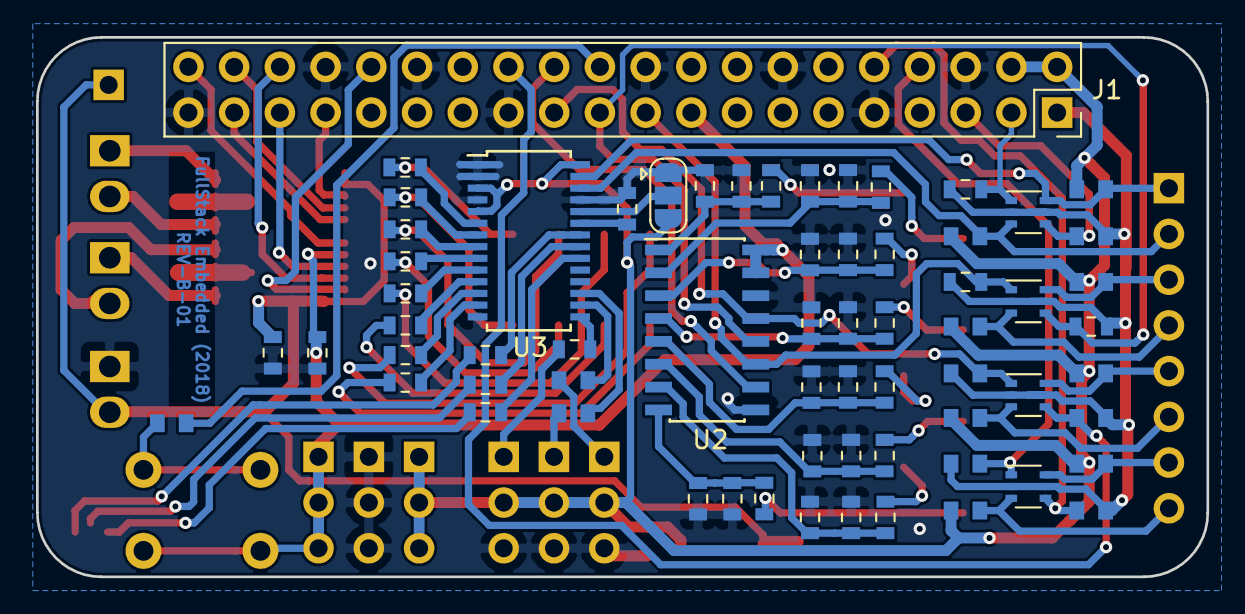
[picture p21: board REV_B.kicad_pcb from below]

Board: 2 copper layers, 65.0 x 30.0 mm, 86 parts (66 on the bottom side), 80 nets.

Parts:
C1, C3: 100n; C_0603_1608Metric
C2: 10u; CP_Elec_4x4.5
C4, C5, C6, C7, C8, C9, C10, C11, C13: 10n; C_0603_1608Metric
C12: 0.33u; C_0603_1608Metric
J1: RaspberryPi; PinSocket_2x20_P2.54mm_Vertical
J2, J3, J4: Conn_01x02; Molex_KK-254_AE-6410-02A_1x02_P2.54mm_Vertical
J5: Conn_01x08; PinHeader_1x08_P2.54mm_LongPad_Vertical_SMD_Pin1Right
J6: Conn_02x04_Counter_Clockwise; PinHeader_2x04_P2.54mm_Vertical_SMD
J7, J8, J9, J10, J11, J12: Conn_01x03; PinHeader_1x03_P2.54mm_Vertical
J13: Conn_01x08; PinHeader_1x08_P2.54mm_Vertical
J14: Conn_01x01; PinSocket_1x01_P2.54mm_Vertical
JP1: Jumper_3_Open; SolderJumper-3_P1.3mm_Open_RoundedPad1.0x1.5mm
R1, R2, R3, R4, R10, R11, R12, R13, R48: 1k; R_0603_1608Metric
R5, R6, R7, R8, R9, R30, R31, R32, R33, R34, R35, R36, R37, R38, R39, R40, R41, R42, R43, R44, R45: 10k; R_0603_1608Metric
R14, R15, R16, R17: 22k; R_0603_1608Metric
R18, R19, R20, R21, R22, R23, R24, R25, R26, R27, R28, R29, R46, R47: 220; R_0603_1608Metric
SW1: SW_Push; SW_PUSH_6mm
U1: TB6612FNG; SSOP-24_5.3x8.2mm_P0.65mm
U2: MCP3008; SOIC-16_3.9x9.9mm_P1.27mm
U3: PCA9685PW; TSSOP-28_4.4x9.7mm_P0.65mm
U4, U5, U6, U7: BSS138PS; SOT-363_SC-70-6
U8: L7805; TO-252-3_TabPin2
U9: ASMT-YTB7-0AA02; LED_Avago_PLCC6_3x2.8mm

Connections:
+3V3: C1.1, J1.1, J1.17, J11.1, J11.2, J11.3, R30.1, R31.1, R32.1, R33.1, R34.1, R35.1, R36.1, R37.1, SW1.2, U1.20, U2.15, U2.16, U4.2, U4.5, U5.2, U5.5, U6.2, U6.5, U7.2, U7.5
+5V: C13.1, J1.2, J1.4, J7.2, J8.2, J9.2, J10.1, J10.2, J10.3, JP1.3, R38.1, R39.1, R40.1, R41.1, R42.1, R43.1, R44.1, R45.1, U3.3, U3.5, U3.28, U8.3
+BATT: C2.1, C3.1, C12.1, J2.2, J14.1, U1.13, U1.14, U1.24, U8.1
GND: C1.2, C2.2, C3.2, C4.2, C5.2, C6.2, C7.2, C8.2, C9.2, C10.2, C11.2, C12.2, C13.2, J1.6, J1.9, J1.14, J1.20, J1.25, J1.30, J1.34, J1.39, J2.1, J7.3, J8.3, J9.3, J12.1, J12.2, J12.3, JP1.1, R1.2, R2.2, R3.2, R4.2, R5.2, R6.2, R7.2, R8.2, R9.1, U1.3, U1.4, U1.9, U1.10, U1.18, U2.9, U2.14, U3.1, U3.2, U3.4, U3.14, U3.25, U8.2, U9.1, U9.2, U9.3
I2C1_SCL_HV: J13.2, R43.2, U3.26, U5.3
I2C1_SCL_LV: J1.5, R33.2, U5.4
I2C1_SDA_HV: J13.1, R39.2, U3.27, U5.6
I2C1_SDA_LV: J1.3, R32.2, U5.1
unnamed: C4.1, R1.1, R10.2, U2.1
unnamed: C5.1, R2.1, R11.2, U2.2
unnamed: C6.1, R3.1, R12.2, U2.3
unnamed: C7.1, R4.1, R13.2, U2.4
unnamed: C8.1, R5.1, R14.2, U2.5
unnamed: C9.1, R6.1, R15.2, U2.6
unnamed: C10.1, R7.1, R16.2, U2.7
unnamed: C11.1, R8.1, R17.2, U2.8
unnamed: J1.24, U2.10
unnamed: J1.32, U1.23
unnamed: J1.33, U1.15
unnamed: J1.35, U1.21
unnamed: J1.36, U1.22
unnamed: J1.37, U1.17
unnamed: J1.38, U1.16
unnamed: J1.40, U1.19
unnamed: J3.1, U1.1, U1.2
unnamed: J3.2, U1.5, U1.6
unnamed: J4.1, U1.11, U1.12
unnamed: J4.2, U1.7, U1.8
unnamed: J5.1, R10.1
unnamed: J5.2, R11.1
unnamed: J5.3, R12.1
unnamed: J5.4, R13.1
unnamed: J5.5, R14.1
unnamed: J5.6, R15.1
unnamed: J5.7, R16.1
unnamed: J5.8, R17.1
unnamed: J6.1, R21.1
unnamed: J6.2, R22.1
unnamed: J6.3, R23.1
unnamed: J6.4, R24.1
unnamed: J6.5, R25.1
unnamed: J6.6, R26.1
unnamed: J6.7, R27.1
unnamed: J6.8, R28.1
unnamed: J7.1, R47.1
unnamed: J8.1, R46.1
unnamed: J9.1, R29.1
unnamed: J13.3, R38.2, U4.6
unnamed: J13.4, R42.2, U4.3
unnamed: J13.5, R40.2, U6.6
unnamed: J13.6, R44.2, U6.3
unnamed: J13.7, R41.2, U7.6
unnamed: J13.8, R45.2, U7.3
unnamed: JP1.2, U3.24
unnamed: R9.2, U3.23
unnamed: R18.1, U9.6
unnamed: R18.2, U3.22
unnamed: R19.1, U9.5
unnamed: R19.2, U3.21
unnamed: R20.1, U9.4
unnamed: R20.2, U3.20
unnamed: R21.2, U3.6
unnamed: R22.2, U3.7
unnamed: R23.2, U3.8
unnamed: R24.2, U3.9
unnamed: R25.2, U3.10
unnamed: R26.2, U3.11
unnamed: R27.2, U3.12
unnamed: R28.2, U3.13
unnamed: R29.2, U3.15
unnamed: R46.2, U3.16
unnamed: R47.2, U3.17
unnamed: R48.2, SW1.1
PUSH_BUTTON: J1.22, R48.1
SPI0_CLK_LV: J1.23, R34.2, U2.13, U6.1
SPI0_CS1_LV: J1.26, R35.2, U6.4
SPI0_MISO_LV: J1.21, R31.2, U2.12, U4.4
SPI0_MOSI_LV: J1.19, R30.2, U2.11, U4.1
UART_RX_LV: J1.10, R37.2, U7.4
UART_TX_LV: J1.8, R36.2, U7.1

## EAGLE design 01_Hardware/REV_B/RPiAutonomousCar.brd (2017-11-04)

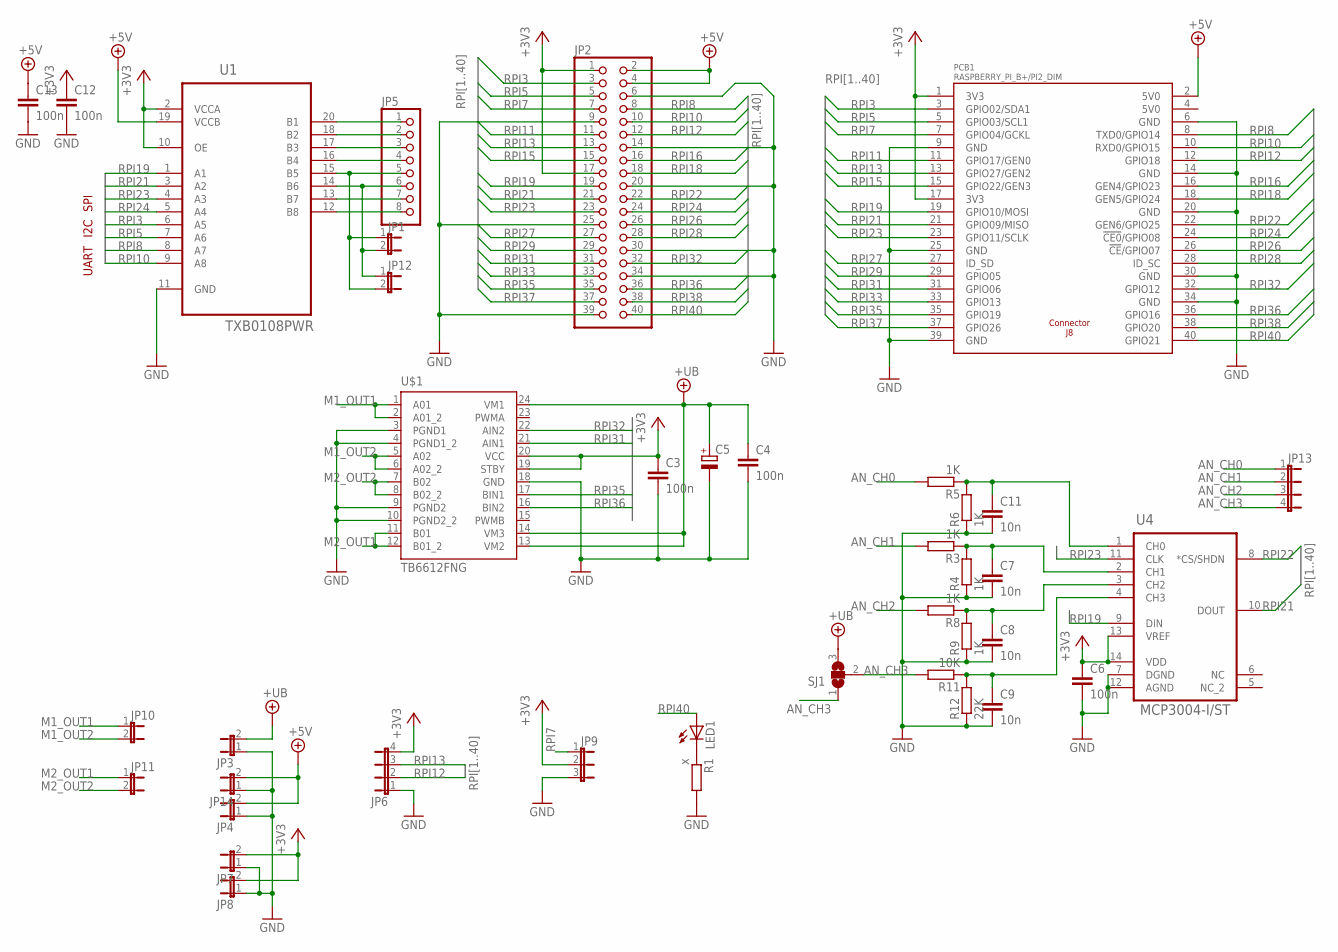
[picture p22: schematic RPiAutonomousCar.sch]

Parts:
C3, C4, C6, C12, C13: 100n; C0603
C5: CPOL-EU153CLV-0405; 153CLV-0405
C7, C8, C9, C11: 10n; C0603
JP1, JP3, JP4, JP7, JP8, JP10, JP11, JP12, JP14: JP1E; JP1
JP2: PINHD-2X20; 2X20
JP5: PINHD-1X8; 1X08
JP6, JP13: JP4E; JP4
JP9: JP2E; JP2
LED1: LEDSML0603; SML0603
PCB1: RASPBERRY_PI_B+/PI2_DIM; RASPBERRY_PI_BPLUS_HEADER_ONLY
R1: x; R0603
R3, R4, R5, R6, R8, R9: 1K; R0603
R11: 10K; R0603
R12: 22K; R0603
SJ1: SJ2W; SJ_2
U1: TXB0108PWR; SOP65P640X120-20N
U4: MCP3004-I/ST; SOP65P640X120-14N
U$1: TB6612FNG; SSOP24

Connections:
5V0: PCB1.4 (5V0)
+3V3: C3.1, C6.1, C12.1, JP2.1, JP2.17, JP6.4, JP7.2, JP8.2, JP9.2, PCB1.1 (3V3), PCB1.17 (3V3), U1.2 (VCCA), U1.10 (OE), U4.13 (VREF), U4.14 (VDD), U$1.19 (STBY), U$1.20 (VCC)
+5V: C13.1, JP2.2, JP2.4, JP4.2, JP14.2, PCB1.2 (5V0), U1.19 (VCCB)
+UB: C4.1, C5.+, JP3.2, SJ1.3, U$1.13 (VM2), U$1.14 (VM3), U$1.24 (VM1)
AN_CH0: JP13.1, R5.2
AN_CH1: JP13.2, R3.2
AN_CH2: JP13.3, R8.2
AN_CH3: JP13.4, R11.2, SJ1.1, SJ1.2
GND: C3.2, C4.2, C5.-, C6.2, C7.2, C8.2, C9.2, C11.2, C12.2, C13.2, JP2.6, JP2.9, JP2.14, JP2.20, JP2.25, JP2.30, JP2.34, JP2.39, JP3.1, JP4.1, JP6.1, JP7.1, JP8.1, JP9.3, JP14.1, PCB1.6 (GND), PCB1.9 (GND), PCB1.14 (GND), PCB1.20 (GND), PCB1.25 (GND), PCB1.30 (GND), PCB1.34 (GND), PCB1.39 (GND), R1.2, R4.1, R6.1, R9.1, R12.1, U1.11 (GND), U4.7 (DGND), U4.12 (AGND), U$1.3 (PGND1), U$1.4 (PGND1_2), U$1.9 (PGND2), U$1.10 (PGND2_2), U$1.18 (GND)
M1_OUT1: JP10.1, U$1.1 (A01), U$1.2 (A01_2)
M1_OUT2: JP10.2, U$1.5 (A02), U$1.6 (A02_2)
M2_OUT1: JP11.1, U$1.11 (B01), U$1.12 (B01_2)
M2_OUT2: JP11.2, U$1.7 (B02), U$1.8 (B02_2)
unnamed: JP5.8, U1.12 (B8)
unnamed: JP5.7, U1.13 (B7)
unnamed: JP1.2, JP5.6, JP12.1, U1.14 (B6)
unnamed: JP5.4, U1.16 (B4)
unnamed: JP5.3, U1.17 (B3)
unnamed: JP5.2, U1.18 (B2)
unnamed: JP5.1, U1.20 (B1)
unnamed: C11.1, R5.1, R6.2, U4.1 (CH0)
unnamed: LED1.C, R1.1
unnamed: C7.1, R3.1, R4.2, U4.2 (CH1)
unnamed: C8.1, R8.1, R9.2, U4.3 (CH2)
unnamed: C9.1, R11.1, R12.2, U4.4 (CH3)
unnamed: JP1.1, JP5.5, JP12.2, U1.15 (B5)
RPI3: JP2.3, PCB1.3 (GPIO02/SDA1), U1.6 (A5)
RPI5: JP2.5, PCB1.5 (GPIO03/SCL1), U1.7 (A6)
RPI7: JP2.7, JP9.1, PCB1.7 (GPIO04/GCKL)
RPI8: JP2.8, PCB1.8 (TXD0/GPIO14), U1.8 (A7)
RPI10: JP2.10, PCB1.10 (RXD0/GPIO15), U1.9 (A8)
RPI11: JP2.11, PCB1.11 (GPIO17/GEN0)
RPI12: JP2.12, JP6.2, PCB1.12 (GPIO18)
RPI13: JP2.13, JP6.3, PCB1.13 (GPIO27/GEN2)
RPI15: JP2.15, PCB1.15 (GPIO22/GEN3)
RPI16: JP2.16, PCB1.16 (GEN4/GPIO23)
RPI18: JP2.18, PCB1.18 (GEN5/GPIO24)
RPI19: JP2.19, PCB1.19 (GPIO10/MOSI), U1.1 (A1), U4.9 (DIN)
RPI21: JP2.21, PCB1.21 (GPIO09/MISO), U1.3 (A2), U4.10 (DOUT)
RPI22: JP2.22, PCB1.22 (GEN6/GPIO25), U4.8 (*CS/SHDN)
RPI23: JP2.23, PCB1.23 (GPIO11/SCLK), U1.4 (A3), U4.11 (CLK)
RPI24: JP2.24, PCB1.24 (!CE0!/GPIO08), U1.5 (A4)
RPI26: JP2.26, PCB1.26 (!CE!/GPIO07)
RPI27: JP2.27, PCB1.27 (ID_SD)
RPI28: JP2.28, PCB1.28 (ID_SC)
RPI29: JP2.29, PCB1.29 (GPIO05)
RPI31: JP2.31, PCB1.31 (GPIO06), U$1.21 (AIN1)
RPI32: JP2.32, PCB1.32 (GPIO12), U$1.22 (AIN2)
RPI33: JP2.33, PCB1.33 (GPIO13)
RPI35: JP2.35, PCB1.35 (GPIO19), U$1.17 (BIN1)
RPI36: JP2.36, PCB1.36 (GPIO16), U$1.16 (BIN2)
RPI37: JP2.37, PCB1.37 (GPIO26)
RPI38: JP2.38, PCB1.38 (GPIO20)
RPI40: JP2.40, LED1.A, PCB1.40 (GPIO21)

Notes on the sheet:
SPI
I2C
UART

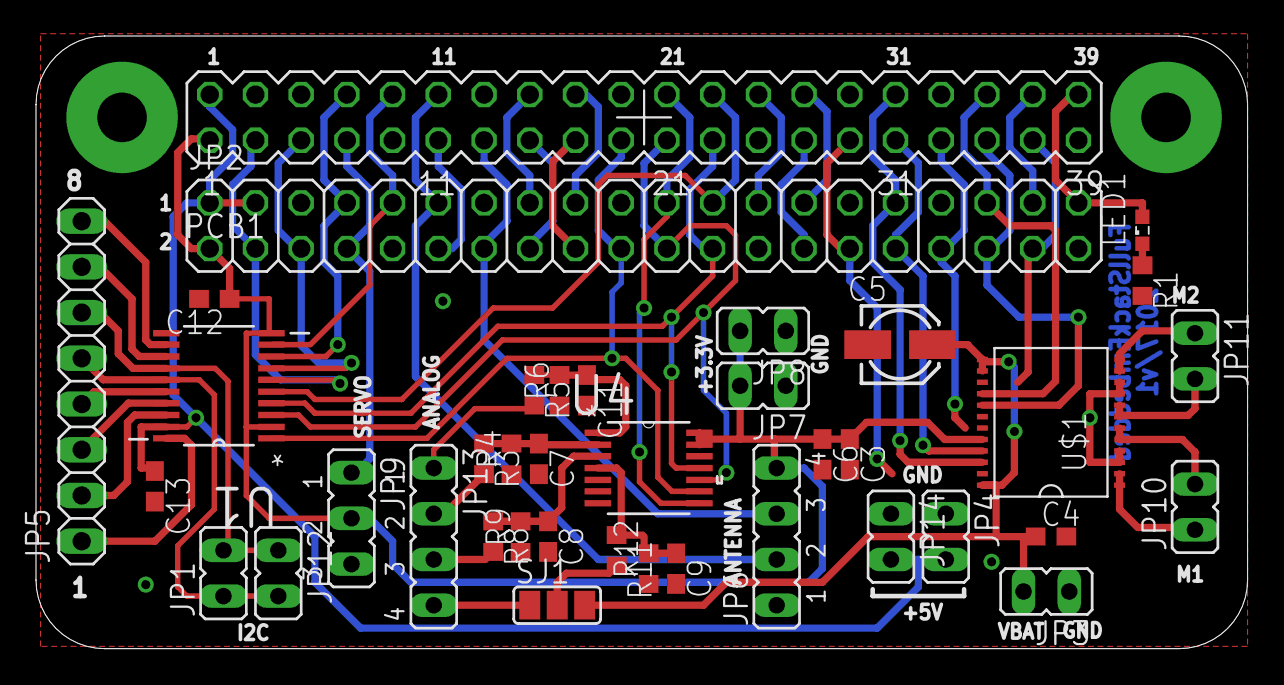
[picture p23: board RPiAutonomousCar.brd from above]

Board: 2 copper layers, 67.3 x 34.0 mm, 39 parts (0 on the bottom side), 53 nets.

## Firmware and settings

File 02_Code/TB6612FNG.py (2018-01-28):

#!/usr/bin/python
import time
import sys
import wiringpi as gpio

class TB6612FNG():
    """
    Class to represent TB6612FNG DC Motor driver
    """

    def __init__(self):
        # Initialise inputs & outputs pins
        self._M1Dir1Pin = 6
        self._M1Dir2Pin = 12
        self._M1PWMPin_annex  = 5  #solve error mapping (Vers.01)
        self._M1PWMPin  = 18
        self._M2Dir1Pin = 19
        self._M2Dir2Pin = 16
        self._M2PWMPin_annex  = 26 #solve error mapping (Vers.01)
        self._M2PWMPin = 13
        self._STBY =  20

        # Configure TB6612GNG Pins
        gpio.wiringPiSetupGpio ()
        gpio.pinMode(self._M1Dir1Pin,1)
        gpio.pinMode(self._M1Dir2Pin,1)
        gpio.pinMode(self._M1PWMPin,2)
        gpio.pinMode(self._M1PWMPin_annex, 0)
        gpio.pinMode(self._M2Dir1Pin,1)
        gpio.pinMode(self._M2Dir2Pin,1)
        gpio.pinMode(self._M2PWMPin,2)
        gpio.pinMode(self._M2PWMPin_annex, 0)
        gpio.pinMode(self._STBY, 1)

    def getDC(self, dc):
        return (1023*dc)/100

    def M1CounterClkwise(self):
        gpio.digitalWrite(self._M1Dir1Pin, 0)
        gpio.digitalWrite(self._M1Dir2Pin, 1)

    def M1Clkwise(self):
        gpio.digitalWrite(self._M1Dir1Pin, 1)
        gpio.digitalWrite(self._M1Dir2Pin, 0)

    def M2CounterClkwise(self):
        gpio.digitalWrite(self._M2Dir1Pin, 0)
        gpio.digitalWrite(self._M2Dir2Pin, 1)

    def M2Clkwise(self):
        gpio.digitalWrite(self._M2Dir1Pin, 1)
        gpio.digitalWrite(self._M2Dir2Pin, 0)

    def forward(self, dutyCycle = 20):
        self.M1CounterClkwise()
        self.M2Clkwise()
        gpio.pwmWrite(self._M1PWMPin, self.getDC(dutyCycle))
        gpio.pwmWrite(self._M2PWMPin, self.getDC(dutyCycle))
        gpio.digitalWrite(self._STBY, 1)

    def reverse(self, dutyCycle = 20):
        self.M1Clkwise()
        self.M2CounterClkwise()
        gpio.pwmWrite(self._M1PWMPin, self.getDC(dutyCycle))
        gpio.pwmWrite(self._M2PWMPin, self.getDC(dutyCycle))
        gpio.digitalWrite(self._STBY, 1)

    def right(self, dutyCycle = 20):
        self.M1CounterClkwise()
        self.M2CounterClkwise()
        gpio.pwmWrite(self._M1PWMPin, self.getDC(dutyCycle))
        gpio.pwmWrite(self._M2PWMPin, self.getDC(dutyCycle))
        gpio.digitalWrite(self._STBY, 1)

    def left(self, dutyCycle = 20):
        self.M1Clkwise()
        self.M2Clkwise()
        gpio.pwmWrite(self._M1PWMPin, self.getDC(dutyCycle))
        gpio.pwmWrite(self._M2PWMPin, self.getDC(dutyCycle))
        gpio.digitalWrite(self._STBY, 1)

    def stop(self):
        gpio.digitalWrite(self._M1Dir1Pin, 0)
        gpio.digitalWrite(self._M1Dir2Pin, 0)
        gpio.digitalWrite(self._M2Dir1Pin, 0)
        gpio.digitalWrite(self._M2Dir2Pin, 0)
        gpio.pwmWrite(self._M1PWMPin, 0)
        gpio.pwmWrite(self._M2PWMPin, 0)
        gpio.digitalWrite(self._STBY, 0)

    def destroy(self):
        gpio.pwmWrite(self._M1PWMPin , 0)
        gpio.pinMode (self._M1PWMPin , 0)
        gpio.pwmWrite(self._M2PWMPin , 0)
        gpio.pinMode (self._M2PWMPin , 0)
        gpio.pinMode (self._M1Dir1Pin, 0)
        gpio.pinMode (self._M1Dir2Pin, 0)
        gpio.pinMode (self._M2Dir1Pin, 0)
        gpio.pinMode (self._M2Dir2Pin, 0)


if __name__ == '__main__':
    tb6612fng = TB6612FNG()
    try:
        while True:

            print "forward"
            tb6612fng.forward()
            time.sleep(3)

            tb6612fng.stop()
            time.sleep(3)

            print "reverse"
            tb6612fng.reverse()
            time.sleep(3)

            tb6612fng.stop()
            time.sleep(3)

            print "left"
            tb6612fng.left()
            time.sleep(3)

            tb6612fng.stop()
            time.sleep(3)

            print "right"
            tb6612fng.right()
            time.sleep(3)

            tb6612fng.stop()
            time.sleep(3)
            print "Done!"

    except KeyboardInterrupt:
        tb6612fng.destroy()
        sys.exit(0)

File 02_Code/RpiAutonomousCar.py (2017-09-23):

#!/usr/bin/env python()
from threading import Thread
import RPi.GPIO as GPIO
from HCSR04    import HCSR04
from MCP3004   import MCP3004
from TB6612FNG import TB6612FNG
from IRModule import IRModule
from LED       import LED
import time


class HeartBeat:
    def __init__(self):
        self._running = True
        self._LED = LED()

    def terminate(self):
        self._running = False

    def run(self):
        while self._running:
            self._LED.ledOn()
            time.sleep(0.5)
            self._LED.ledOff()
            time.sleep(0.5)

class AutonomousDrive:
    def __init__(self):
        self._running = True
        self._USonic = HCSR04()
        self._MotorDrive = TB6612FNG()

    def terminate(self):
        self._running = False

    def run(self):
        DutyCycle = 4
        while self._running:
            qualifier,distance =  self._USonic.get_averageDistance()
            if qualifier == 1:
                if distance < 20:
                    self._MotorDrive.stop()
                    time.sleep(0.01)
                    self._MotorDrive.reverse(DutyCycle-2)
                    time.sleep(0.2)
                    self._MotorDrive.left(DutyCycle-2)
                    time.sleep(0.2)
                    self._MotorDrive.forward(DutyCycle)
                else:
                    self._MotorDrive.forward()
            else:
                pass


class LineFollower:
    def __init__(self):
        self._running = True
        self._IR = IRModule()
        self._MotorDrive = TB6612FNG()
        self._USonic = HCSR04()
        self._loopCount = 0
        self._IRNbr = 2

    def terminate(self):
        self._running = False

    def run(self):
        statusLeft  = False
        statusRight = False
        dc = 2
        USonicDist = 1000
        print "running..."

        if self._IRNbr == 2:
            while self._running:
                #read USonic sensor

                #if self._loopCount%2  == True:
                    #qualifier,dis = self._USonic.get_averageDistance()
                    #if qualifier == 1:
                        #USonicDist = dis
                    #else:
                        #print "wrong measurement"
                #self._loopCount += 1

                #read IR Sensor
                statusLeft  = self._IR.getStatusMiddle()
                statusRight = self._IR.getStatusRight()

                if USonicDist > 10:
                    if statusLeft and statusRight:
                        self._MotorDrive.forward(dc)
                    elif statusLeft:
                        # line on the left => move left
                        self._MotorDrive.left(dc-1)
                    elif statusRight:
                        # line on the right => move right
                        self._MotorDrive.right(dc-1)
                else:
                    self._MotorDrive.stop(1)
                    print "Obstacle detected at "+ str(USonicDist)
        else:
            print "Nooo"

            """
            while self._running:
                if self._IR.getStatusLeft() == True:
                    statusLeft = 0b100
                else:
                    statusLeft = 0
                if self._IR.getStatusMiddle():
                    statusMiddle = 0b010
                else:
                    statusMiddle = 0
                if self._IR.getStatusRight():
                    statusRight  = 0b001
                else:
                    statusRight  = 0

                var = statusLeft+statusMiddle+statusRight
                """


if __name__ == "__main__":

    try:
        Th1 = HeartBeat()
        HeartBeatThread = Thread(target = Th1.run)
        HeartBeatThread.start()

        Th2 = LineFollower()
        RpiAutCarThread = Thread(target = Th2.run)
        RpiAutCarThread.start()

        while True:
            pass
    except KeyboardInterrupt:
        Th1.terminate()
        Th2.terminate()
        GPIO.cleanup()

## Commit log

2017-05-26 routing ...
    [AutonousCarPinout.ods, RPiAutonomousCar.brd, RPiAutonomousCar.sch]
2017-05-29 rounting/Pinout minor changes
    [AutonousCarPinout.ods, RPiAutonomousCar.brd, RPiAutonomousCar.sch]
2017-05-29 routing almost done
    [AutonousCarPinout.ods, RPiAutonomousCar.brd]
2017-05-30 routing done
    [RPiAutonomousCar.brd]
2017-06-05 ready for review
    [RPiAutonomousCar.brd, RPiAutonomousCar.sch]
2017-06-07 routing done. Ready to order
    [RPiAutonomousCar.brd, RPiAutonomousCar.sch]
2017-06-10 Version 1 done
    [RPiAutonomousCar.brd]
2017-06-17 Restructure Directories
    [Order.ods, RPiAutonomousCar.brd, RPiAutonomousCar.sch]
2017-06-18 add cost calculation
    [Order.ods]
2017-06-24 driver HCSR04 LED MCP3004 TB6612FNG added
2017-06-24 moinor corrections
    [AutonousCarPinout.ods, Order.ods, RPiAutonomousCar.brd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]
2017-06-24 servo driver added
2017-08-05 minor changes
    [Order.ods]
2017-09-15 Thread based Line follower added
2017-10-30 Hardware PWM support
2017-11-04 HW Pwm modifications
    [AutonousCarPinout.ods, AutonousCarPinout_V02.ods, RPiAutonomousCar.brd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]
2018-01-21 (1) Changes from Lome and Ghana (2) Board Revision B started
    [AutonousCarPinout_V02.ods, Order.ods, REV_B.kicad_pcb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]
2018-01-28 Designing RevB
    [AutonousCarPinout_V02.ods, REV_B.kicad_pcb, REV_B.sch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]
2018-02-04 Work in Progress
    [REV_B.kicad_pcb, REV_B.sch]
2018-02-04 Brd redo due to kicad update
    [REV_B.kicad_pcb, REV_B.sch]
2018-04-04 kicad version REVB added
    [REV_B.csv, REV_B.kicad_pcb, REV_B.sch]
2018-04-22 Routing started
    [REV_B.kicad_pcb, REV_B.sch]
2018-04-24 remaning resistors added to PCA9685 w/ routing
    [REV_B.kicad_pcb]
2018-04-30 Routing in progress
    [REV_B.kicad_pcb]
2018-05-27 Taster added. routing not done
    [REV_B.kicad_pcb, REV_B.sch]
2018-06-08 Routing done. Ready to be manufactured
    [REV_B.kicad_pcb, REV_B.sch, REV_B_Order.ods]
2018-06-09 Last Modification: Jumper J5 long pad smd used
    [REV_B.kicad_pcb, REV_B.sch]
2018-09-30 REVB-02 implemented. (1) Rpi header mirrored (2) New Switch added (THR) (3) New RGB LED
    [AutonousCarPinout_V02.ods, REV_B.kicad_pcb, REV_B.sch]
